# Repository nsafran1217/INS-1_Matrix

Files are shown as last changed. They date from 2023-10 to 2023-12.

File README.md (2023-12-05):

# INS-1_Matrix
Matrix Display made with INS-1 Nixie Tube indicators

More info at: https://nsafran.com/ins-1-nixie-tube-matrix.html

ArduinoLibrary contains the library to use the matrix. A description of the animation data format is provided in the docs folder.

INS-1_MatrixDesigner contains a c# WinForms app to help design animations for the display. You can save and load animations from JSON files with this app. This is not a polished application and it may crash if you do something I didn't think of.
You will just copy and paste the array definition from the output text box into your Arduino code.

INS-1 Matrix Board directory contains the KiCAD files as designed. I recommend moving the resistors for the indicators away from the plated through hole. When I had the boards assembled by JLCPCB, the hole was filled with solder. I had to suck the solder out of all the holes that had the resistors right next to the anode hole.

# Completed Boards working


# Unpopulated Board


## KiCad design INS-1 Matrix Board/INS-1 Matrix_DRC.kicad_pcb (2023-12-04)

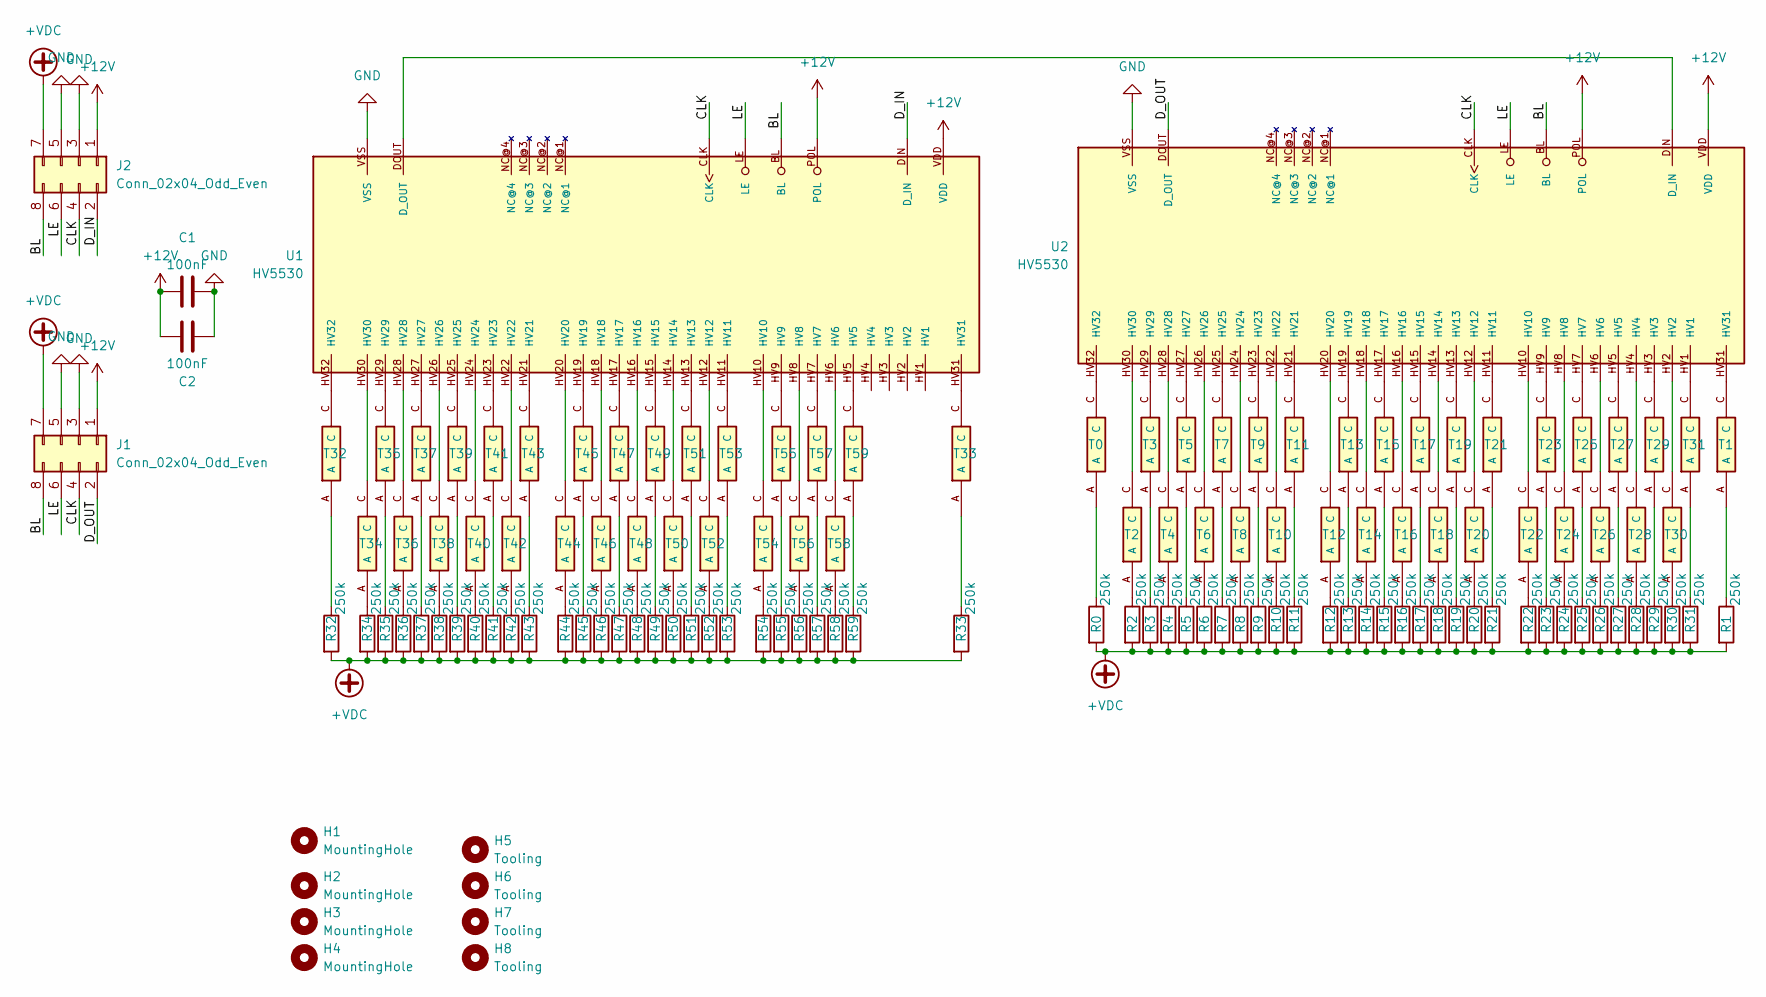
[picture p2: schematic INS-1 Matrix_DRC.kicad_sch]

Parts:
C1, C2: 100nF; C_0805_2012Metric_Pad1.18x1.45mm_HandSolder; LCSC C49678
H1, H2, H3, H4: MountingHole; MountingHole_3.2mm_M3
H5, H6, H7, H8: Tooling; MountingHole_1.152mm
J1, J2: Conn_02x04_Odd_Even; IDC-Header_2x04_P2.54mm_Vertical
R0, R1, R2, R3, R4, R5, R6, R7, R8, R9, R10, R11, R12, R13, R14, R15, R16, R17, R18, R19, R20, R21, R22, R23, R24, R25, R26, R27, R28, R29, R30, R31, R32, R33, R34, R35, R36, R37, R38, R39, R40, R41, R42, R43, R44, R45, R46, R47, R48, R49, R50, R51, R52, R53, R54, R55, R56, R57, R58, R59: 250k; R_0805_2012Metric_Pad1.20x1.40mm_HandSolder; LCSC C5156563
T0, T1, T2, T3, T4, T5, T6, T7, T8, T9, T10, T11, T12, T13, T14, T15, T16, T17, T18, T19, T20, T21, T22, T23, T24, T25, T26, T27, T28, T29, T30, T31, T32, T33, T34, T35, T36, T37, T38, T39, T40, T41, T42, T43, T44, T45, T46, T47, T48, T49, T50, T51, T52, T53, T54, T55, T56, T57, T58, T59: INS-1
U1, U2: HV5530; 44_PQFP_CORRECTED

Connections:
+12V: C1.1, C2.1, J1.1, J2.1, U1.POL, U1.VDD, U2.POL, U2.VDD
+VDC: J1.7, J2.7, R0.2, R1.2, R2.2, R3.2, R4.2, R5.2, R6.2, R7.2, R8.2, R9.2, R10.2, R11.2, R12.2, R13.2, R14.2, R15.2, R16.2, R17.2, R18.2, R19.2, R20.2, R21.2, R22.2, R23.2, R24.2, R25.2, R26.2, R27.2, R28.2, R29.2, R30.2, R31.2, R32.2, R33.2, R34.2, R35.2, R36.2, R37.2, R38.2, R39.2, R40.2, R41.2, R42.2, R43.2, R44.2, R45.2, R46.2, R47.2, R48.2, R49.2, R50.2, R51.2, R52.2, R53.2, R54.2, R55.2, R56.2, R57.2, R58.2, R59.2
/BL: J1.8, J2.8, U1.BL, U2.BL
/CLK: J1.4, J2.4, U1.CLK, U2.CLK
/D_IN: J2.2, U1.DIN (D_IN)
/D_OUT: J1.2, U2.DOUT (D_OUT)
/LE: J1.6, J2.6, U1.LE, U2.LE
GND: C1.2, C2.2, J1.3, J1.5, J2.3, J2.5, U1.VSS, U2.VSS
unnamed: R0.1, T0.A
unnamed: R1.1, T1.A
unnamed: R2.1, T2.A
unnamed: R3.1, T3.A
unnamed: R4.1, T4.A
unnamed: R5.1, T5.A
unnamed: R6.1, T6.A
unnamed: R7.1, T7.A
unnamed: R8.1, T8.A
unnamed: R9.1, T9.A
unnamed: R10.1, T10.A
unnamed: R11.1, T11.A
unnamed: R12.1, T12.A
unnamed: R13.1, T13.A
unnamed: R14.1, T14.A
unnamed: R15.1, T15.A
unnamed: R16.1, T16.A
unnamed: R17.1, T17.A
unnamed: R18.1, T18.A
unnamed: R19.1, T19.A
unnamed: R20.1, T20.A
unnamed: R21.1, T21.A
unnamed: R22.1, T22.A
unnamed: R23.1, T23.A
unnamed: R24.1, T24.A
unnamed: R25.1, T25.A
unnamed: R26.1, T26.A
unnamed: R27.1, T27.A
unnamed: R28.1, T28.A
unnamed: R29.1, T29.A
unnamed: R30.1, T30.A
unnamed: R31.1, T31.A
unnamed: R32.1, T32.A
unnamed: R33.1, T33.A
unnamed: R34.1, T34.A
unnamed: R35.1, T35.A
unnamed: R36.1, T36.A
unnamed: R37.1, T37.A
unnamed: R38.1, T38.A
unnamed: R39.1, T39.A
unnamed: R40.1, T40.A
unnamed: R41.1, T41.A
unnamed: R42.1, T42.A
unnamed: R43.1, T43.A
unnamed: R44.1, T44.A
unnamed: R45.1, T45.A
unnamed: R46.1, T46.A
unnamed: R47.1, T47.A
unnamed: R48.1, T48.A
unnamed: R49.1, T49.A
unnamed: R50.1, T50.A
unnamed: R51.1, T51.A
unnamed: R52.1, T52.A
unnamed: R53.1, T53.A
unnamed: R54.1, T54.A
unnamed: R55.1, T55.A
unnamed: R56.1, T56.A
unnamed: R57.1, T57.A
unnamed: R58.1, T58.A
unnamed: R59.1, T59.A
unnamed: T0.C, U2.HV32
unnamed: T1.C, U2.HV31
unnamed: T2.C, U2.HV30
unnamed: T3.C, U2.HV29
unnamed: T4.C, U2.HV28
unnamed: T5.C, U2.HV27
unnamed: T6.C, U2.HV26
unnamed: T7.C, U2.HV25
unnamed: T8.C, U2.HV24
unnamed: T9.C, U2.HV23
unnamed: T10.C, U2.HV22
unnamed: T11.C, U2.HV21
unnamed: T12.C, U2.HV20
unnamed: T13.C, U2.HV19
unnamed: T14.C, U2.HV18
unnamed: T15.C, U2.HV17
unnamed: T16.C, U2.HV16
unnamed: T17.C, U2.HV15
unnamed: T18.C, U2.HV14
unnamed: T19.C, U2.HV13
unnamed: T20.C, U2.HV12
unnamed: T21.C, U2.HV11
unnamed: T22.C, U2.HV10
unnamed: T23.C, U2.HV9
unnamed: T24.C, U2.HV8
unnamed: T25.C, U2.HV7
unnamed: T26.C, U2.HV6
unnamed: T27.C, U2.HV5
unnamed: T28.C, U2.HV4
unnamed: T29.C, U2.HV3
unnamed: T30.C, U2.HV2
unnamed: T31.C, U2.HV1
unnamed: T32.C, U1.HV32
unnamed: T33.C, U1.HV31
unnamed: T34.C, U1.HV30
unnamed: T35.C, U1.HV29
unnamed: T36.C, U1.HV28
unnamed: T37.C, U1.HV27
unnamed: T38.C, U1.HV26
unnamed: T39.C, U1.HV25
unnamed: T40.C, U1.HV24
unnamed: T41.C, U1.HV23
unnamed: T42.C, U1.HV22
unnamed: T43.C, U1.HV21
unnamed: T44.C, U1.HV20
unnamed: T45.C, U1.HV19
unnamed: T46.C, U1.HV18
unnamed: T47.C, U1.HV17
unnamed: T48.C, U1.HV16
unnamed: T49.C, U1.HV15
unnamed: T50.C, U1.HV14
unnamed: T51.C, U1.HV13
unnamed: T52.C, U1.HV12
unnamed: T53.C, U1.HV11
unnamed: T54.C, U1.HV10
unnamed: T55.C, U1.HV9
unnamed: T56.C, U1.HV8
unnamed: T57.C, U1.HV7
unnamed: T58.C, U1.HV6
unnamed: T59.C, U1.HV5
unnamed: U1.DOUT (D_OUT), U2.DIN (D_IN)

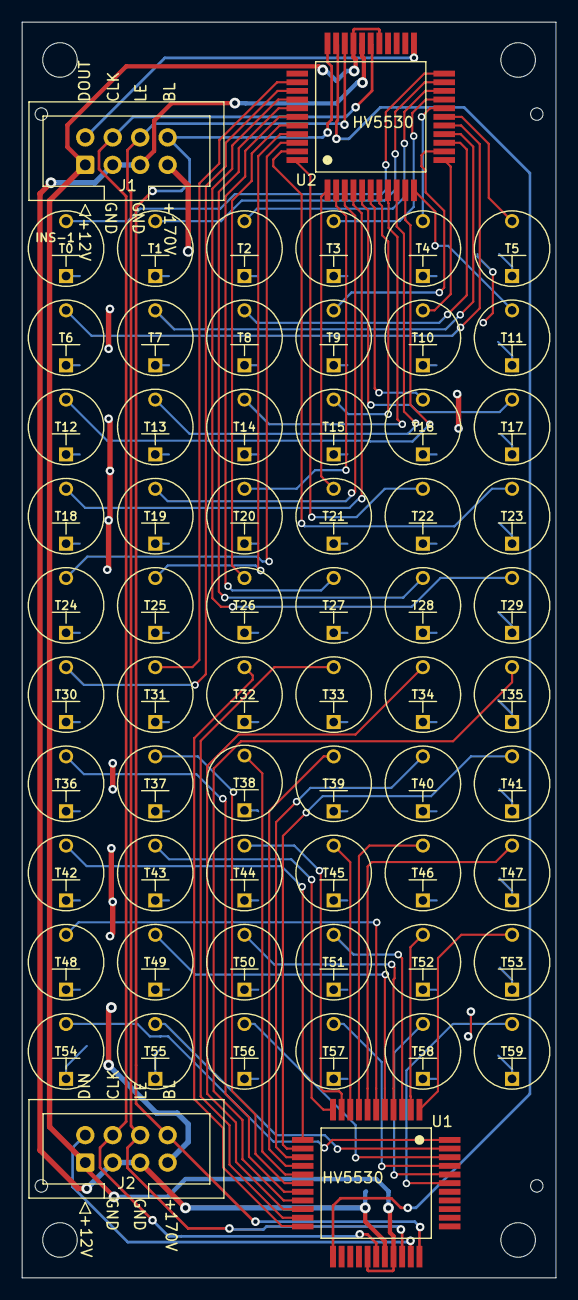
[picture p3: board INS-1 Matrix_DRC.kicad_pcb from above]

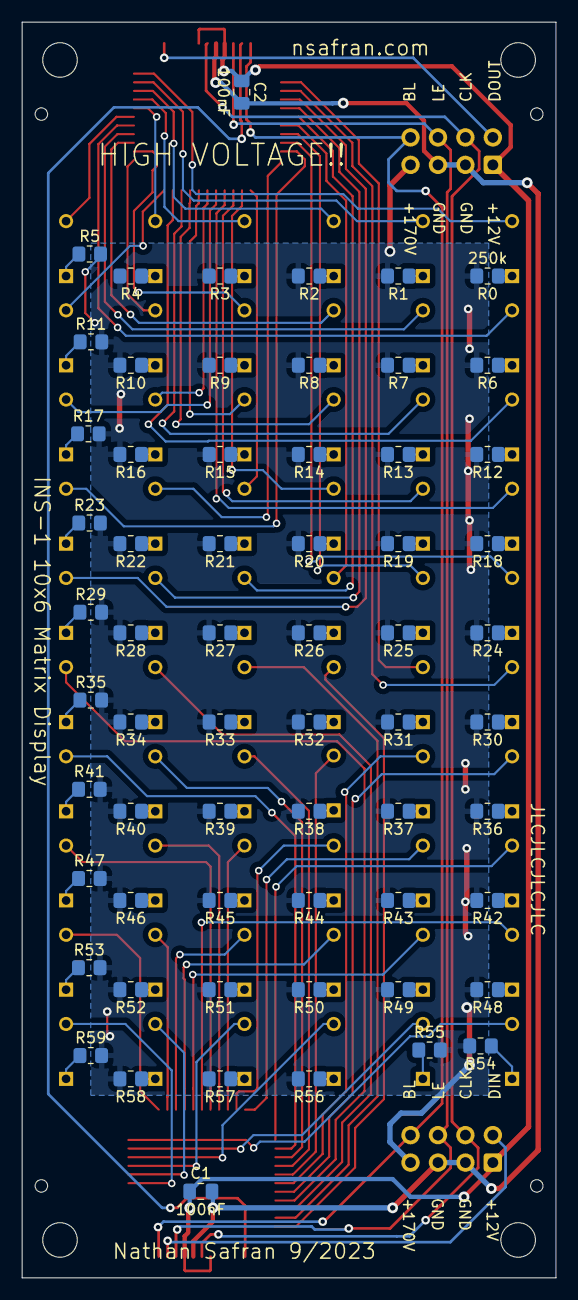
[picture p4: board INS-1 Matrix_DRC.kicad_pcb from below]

Board: 2 copper layers, 49.4 x 116.2 mm, 134 parts (62 on the bottom side), 129 nets.

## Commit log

2023-09-08 Init commit with Board
    [INS-1 Matrix_DRC-BOM.xlsx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]
2023-09-09 Move back to standard arrays that just hold all the frames
2023-09-09 fixing unstaged changes
    [INS-1 Matrix_DRC-B_Cu.gbl, INS-1 Matrix_DRC-B_Mask.gbs, INS-1 Matrix_DRC-B_Paste.gbp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]
2023-09-20 Set blank pin so display comes on
2023-12-04 Change POL pin to connect to 12V
    [INS-1 Matrix_DRC-BOM.xlsx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]
2023-12-04 remove double inversion since board is fixed
